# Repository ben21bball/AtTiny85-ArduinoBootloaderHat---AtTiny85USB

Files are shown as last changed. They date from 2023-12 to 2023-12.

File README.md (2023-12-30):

# AtTiny85-ArduinoBootloaderHat---AtTiny85USB
This repository contains a project for an Arduino hat PCB for downloading a bootloader onto an ATtiny85 microcontroller and a PCB-based USB device for directly sending code to the ATtiny85. All PCB designs were intended to be single-sided PCBs to enable the most amount of tinkerers to create this to save them time with the ATtiny85 bootloading and programming. Hopefully this saves you time and money when making circuits to use the ATtiny85 with the Arduino IDE. 

This is heavily inspired by the following links: https://circuitdigest.com/microcontroller-projects/attiny85-ic-programming-through-usb-using-digispark-bootloader https://circuitdiagrams.in/program-attiny85-microcontroller-using-usb/ 

Credit to the original tinkerers for coming up with these solutions or modifying them. I took issue with a diode orientation in both of these links, as well as wanting to make a compact, affordable single-sided PCB. The circuit diagram for the USB device and the PCB layouts were designed in KiCAD. I will be adding a 3D printed enclosure for the USB device and the files will be added eventually.

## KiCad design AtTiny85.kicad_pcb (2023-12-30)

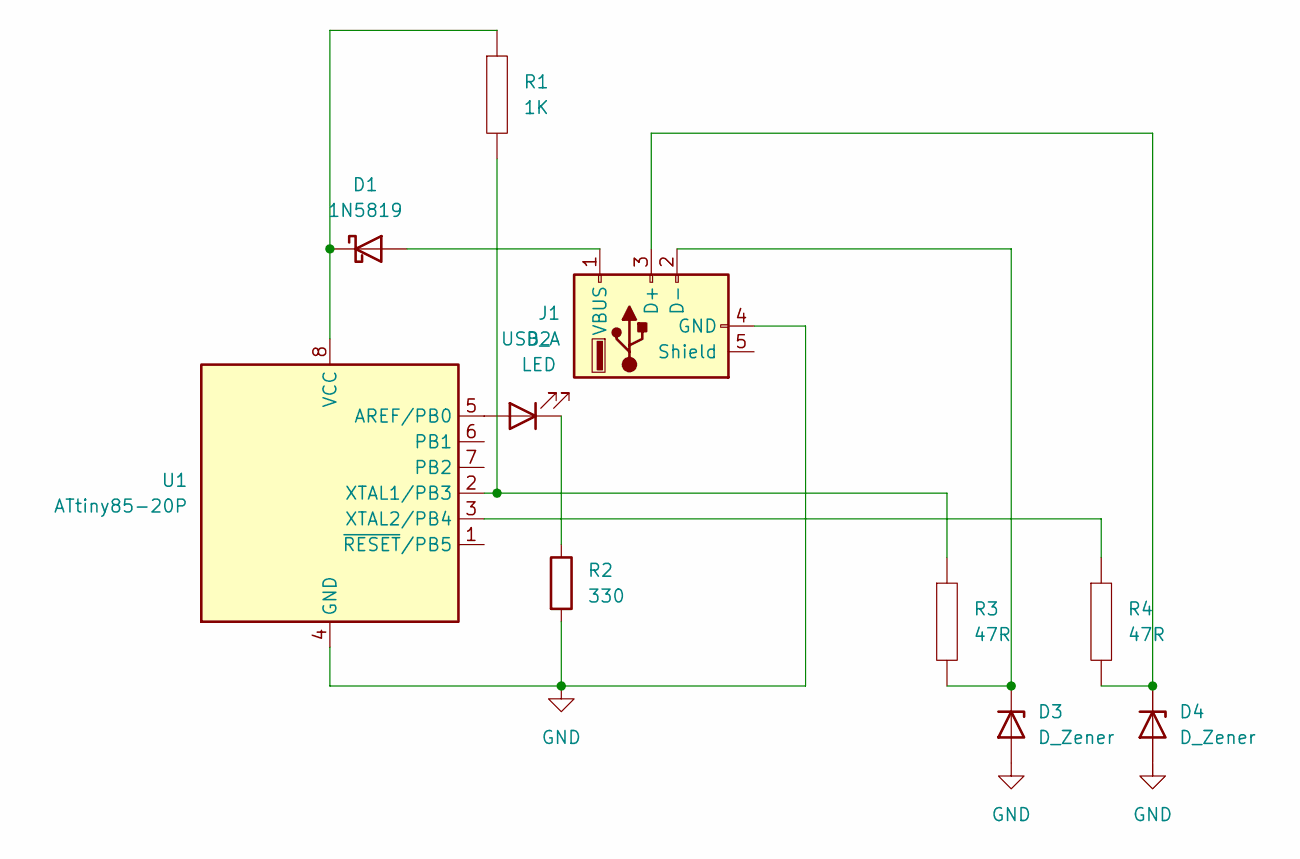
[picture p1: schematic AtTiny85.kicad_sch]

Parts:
D1: 1N5819; D_DO-41_SOD81_P10.16mm_Horizontal
D2: LED; LED_D3.0mm_Clear
D3, D4: D_Zener; D_A-405_P10.16mm_Horizontal
J1: USB_A; USB_A_CNCTech_1001-011-01101_Horizontal
R1: 1K; R_Axial_DIN0207_L6.3mm_D2.5mm_P10.16mm_Horizontal
R2: 330; R_Axial_DIN0207_L6.3mm_D2.5mm_P7.62mm_Horizontal
R3, R4: 47R; R_Axial_DIN0207_L6.3mm_D2.5mm_P7.62mm_Horizontal
U1: ATtiny85-20P; DIP-8_W7.62mm

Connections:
GND: D3.2 (A), D4.2 (A), J1.4 (GND), R2.2, U1.4 (GND)
unnamed: D2.1 (K), R2.1
unnamed: D2.2 (A), U1.5 (AREF/PB0)
unnamed: D3.1 (K), J1.2 (D-), R3.2
unnamed: D4.1 (K), J1.3 (D+), R4.2
unnamed: D1.2 (A), J1.1 (VBUS)
unnamed: D1.1 (K), R1.1, U1.8 (VCC)
unnamed: R1.2, R3.1, U1.2 (XTAL1/PB3)
unnamed: R4.1, U1.3 (XTAL2/PB4)

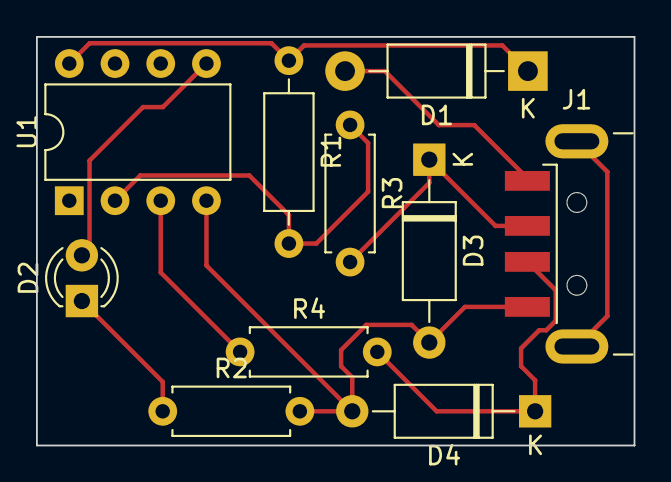
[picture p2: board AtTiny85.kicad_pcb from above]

Board: 2 copper layers, 33.2 x 22.7 mm, 10 parts (0 on the bottom side), 9 nets.

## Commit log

2023-12-30 Add files via upload
    USB device KiCAD project files.
    [AtTiny85.kicad_pcb, AtTiny85.kicad_sch]
2023-12-30 Add files via upload
    Arduino Hat project files from KiCAD
    [AtTiny85ArduinoHat.kicad_pcb, AtTiny85ArduinoHat.kicad_sch]
